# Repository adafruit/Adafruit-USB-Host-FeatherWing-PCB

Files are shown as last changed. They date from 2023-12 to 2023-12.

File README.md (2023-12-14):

## Adafruit USB Host FeatherWing with MAX3421E PCB

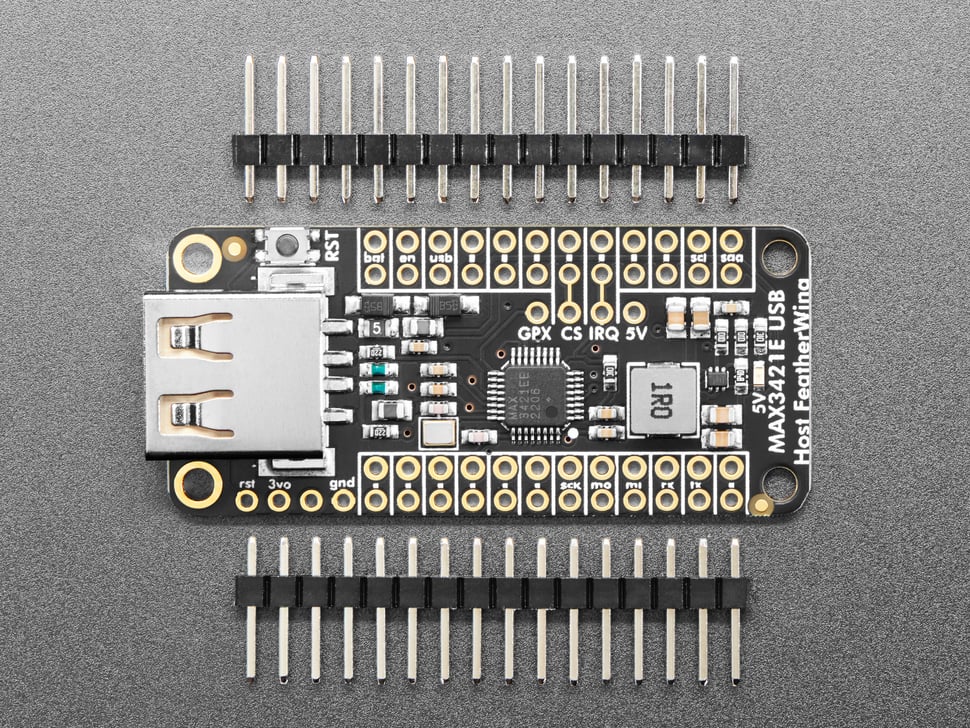
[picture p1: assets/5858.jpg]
<a href="http://www.adafruit.com/products/5858"><br/>
Click here to purchase one from the Adafruit shop</a>

PCB files for the Adafruit USB Host FeatherWing with MAX3421E. 

Format is EagleCAD schematic and board layout
* https://www.adafruit.com/product/5858

### Description

Lots of microcontrollers these days have USB ports on them, to program or debug, act like a keyboard or disk drive, or simply send data between a computer and your firmware. But did you know that you can also add a USB Host port? That means that your microcontroller project can have a keyboard or mouse or disk drive plugged into it - which opens up a huge ecosystem of common off-the-shelf devices that you can now integrate. The Adafruit USB Host FeatherWing makes it easy to add USB Host support, especially now that TinyUSB supports it in the Arduino library as a 'native' interface for host support. 

This Wing uses the MAX3421E - a tried and true USB Host chip. It uses SPI plus an IRQ pin to send data to just about any USB device. Note that because the chip is older, and you're limited to the SPI port speed, you're not going to get blazing 480Mbps high speed data transfer. But for basic HID interfacing, or even reading/writing to a Mass Storage device, it does work quite well. There's a famous USB Host Library that can be used, and it's specialty is AVR support, but also seems to support nRF52 and ESP32. We personally recommend using the TinyUSB Arduino library - however the trade-off is that the chip must have TinyUSB support already which means it's great for RP2040, ESP32-S2 or S3, nRF52840, SAMD21/51 chips. Between the two libraries, just make sure your desired Feather mainboard is supported before purchasing! 

Next to the MAX3421E we have a 5V 1A booster with 500mA fuse, which can provide a nice clean 5V from the USB or Battery power supply. An enable pin is available to power cycle when desired.

Comes as an assembled Wing with some header. Solder on the header and plug into a Feather Mainboard to expand it's capabilities! Don't forget, you need driver support for the MAX3421E (see above for chips that are known working) and unless you're using a generic mouse, keyboard, CDC serial or USB mass storage device you will also need a USB driver that knows how to talk to the device - and writing a driver is non-trivial.

### License

Adafruit invests time and resources providing this open source design, please support Adafruit and open-source hardware by purchasing products from [Adafruit](https://www.adafruit.com)!

Designed by Limor Fried/Ladyada for Adafruit Industries.

Creative Commons Attribution/Share-Alike, all text above must be included in any redistribution. 
See license.txt for additional details.

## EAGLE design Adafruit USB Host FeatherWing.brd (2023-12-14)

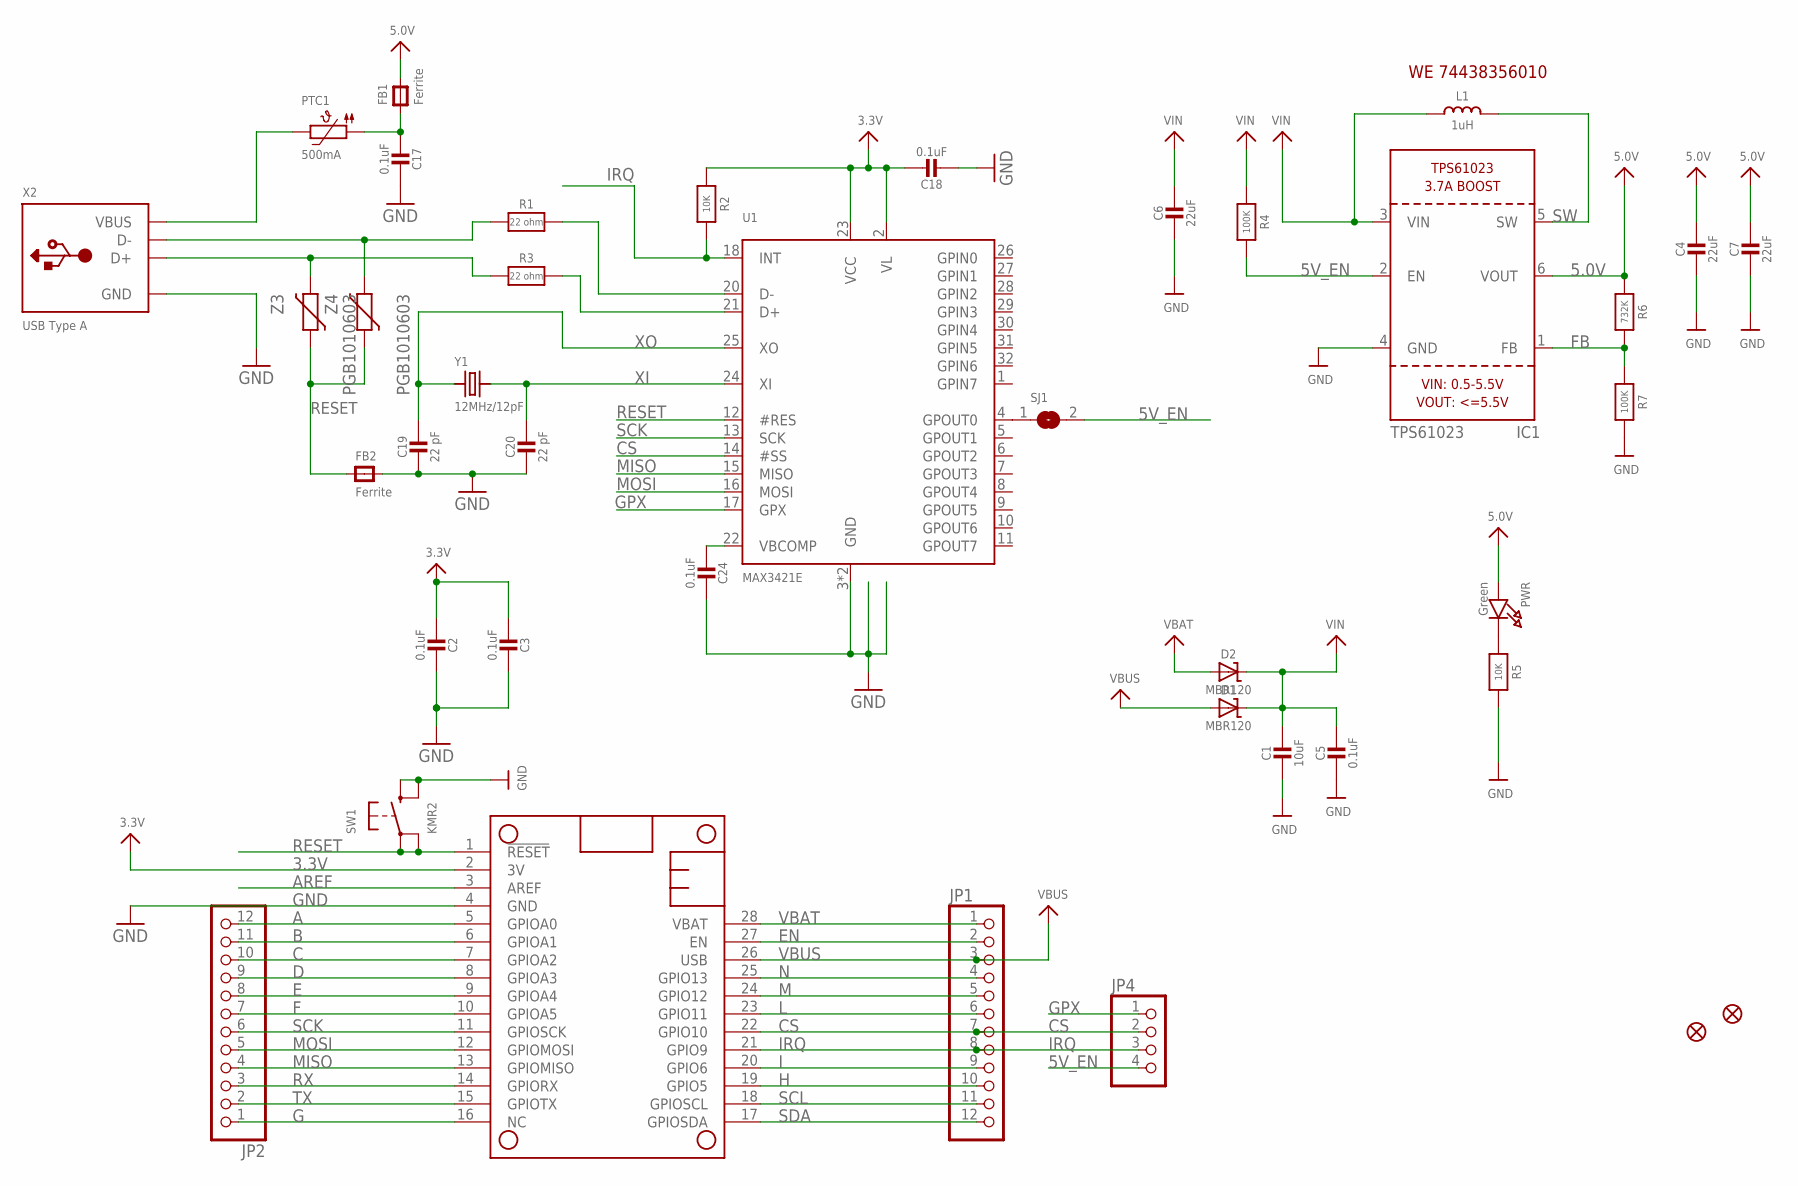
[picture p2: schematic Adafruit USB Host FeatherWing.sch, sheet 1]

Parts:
C1: 10uF; 0805-NO
C2, C3, C5, C17, C18, C24: 0.1uF; 0603-NO
C4, C6, C7: 22uF; 0805-NO
C19, C20: 22 pF; 0603-NO
D1, D2: MBR120; SOD-123
FB1, FB2: Ferrite; 0805-NO
FID1, FID2: FIDUCIAL_1MM
IC1: TPS61023; SOT563
JP1: HEADER-1X12; 1X12_ROUND
JP2: HEADER-1X1276MIL; 1X12_ROUND_76MIL
JP4: HEADER-1X4ROUND; 1X04_ROUND
L1: 1uH; INDUCTOR_5045_SMALLTABS
MS1: FEATHERWING_NODIM
PTC1: 500mA; 0805-NO
PWR: Green; CHIPLED_0603_NOOUTLINE
R1, R3: 22 ohm; 0603-NO
R2, R5: 10K; 0603-NO
R4, R7: 100K; 0603-NO
R6: 732K; 0603-NO
SJ1: SOLDERJUMPER; SOLDERJUMPER_ARROW_NOPASTE
SW1: KMR2; BTN_KMR2_4.6X2.8
U1: MAX3421E; PQFP32_5X5MM
X2: USB Type A; USB_HOST-SMT
Y1: 12MHz/12pF; CRYSTAL_2.5X2
Z3, Z4: PGB1010603; CT/CN0603

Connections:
3.3V: C2.1, C3.1, C18.1, MS1.2 (3V), R2.1, U1.2 (VL), U1.23 (VCC)
5.0V: C4.1, C7.1, FB1.2, IC1.6 (VOUT), PWR.A, R6.1
5V_EN: IC1.2 (EN), JP4.4, R4.2, SJ1.2
A: JP2.12, MS1.5 (GPIOA0)
AREF: MS1.3 (AREF)
B: JP2.11, MS1.6 (GPIOA1)
C: JP2.10, MS1.7 (GPIOA2)
CS: JP1.7, JP4.2, MS1.22 (GPIO10), U1.14 (#SS)
D: JP2.9, MS1.8 (GPIOA3)
E: JP2.8, MS1.9 (GPIOA4)
EN: JP1.2, MS1.27 (EN)
F: JP2.7, MS1.10 (GPIOA5)
FB: IC1.1 (FB), R6.2, R7.1
G: JP2.1, MS1.16 (NC)
GND: C1.2, C2.2, C3.2, C4.2, C5.2, C6.2, C7.2, C17.2, C18.2, C19.1, C20.1, C24.2, FB2.2, IC1.4 (GND), MS1.4 (GND), R5.2, R7.2, SW1.B (S), SW1.B' (S1), U1.3 (GND), U1.19 (GND), X2.GND
GPX: JP4.1, U1.17 (GPX)
H: JP1.10, MS1.19 (GPIO5)
I: JP1.9, MS1.20 (GPIO6)
IRQ: JP1.8, JP4.3, MS1.21 (GPIO9), R2.2, U1.18 (INT)
L: JP1.6, MS1.23 (GPIO11)
M: JP1.5, MS1.24 (GPIO12)
MISO: JP2.4, MS1.13 (GPIOMISO), U1.15 (MISO)
MOSI: JP2.5, MS1.12 (GPIOMOSI), U1.16 (MOSI)
N: JP1.4, MS1.25 (GPIO13)
unnamed: C24.1, U1.22 (VBCOMP)
unnamed: SJ1.1, U1.4 (GPOUT0)
unnamed: FB2.1, Z3.1, Z4.1
unnamed: PWR.C, R5.1
unnamed: R1.1, X2.D-, Z4.2
unnamed: R3.1, X2.D+, Z3.2
unnamed: R1.2, U1.20 (D-)
unnamed: R3.2, U1.21 (D+)
unnamed: PTC1.2, X2.VBUS
unnamed: C17.1, FB1.1, PTC1.1
RESET: MS1.1 (!RESET), SW1.A, SW1.A' (P1), U1.12 (#RES)
RX: JP2.3, MS1.14 (GPIORX)
SCK: JP2.6, MS1.11 (GPIOSCK), U1.13 (SCK)
SCL: JP1.11, MS1.18 (GPIOSCL)
SDA: JP1.12, MS1.17 (GPIOSDA)
SW: IC1.5 (SW), L1.2
TX: JP2.2, MS1.15 (GPIOTX)
VBAT: D2.A, JP1.1, MS1.28 (VBAT)
VBUS: D1.A, JP1.3, MS1.26 (USB)
VIN: C1.1, C5.1, C6.1, D1.C, D2.C, IC1.3 (VIN), L1.1, R4.1
XI: C20.2, U1.24 (XI), Y1.3 (2)
XO: C19.2, U1.25 (XO), Y1.1

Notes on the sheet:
WE 74438356010

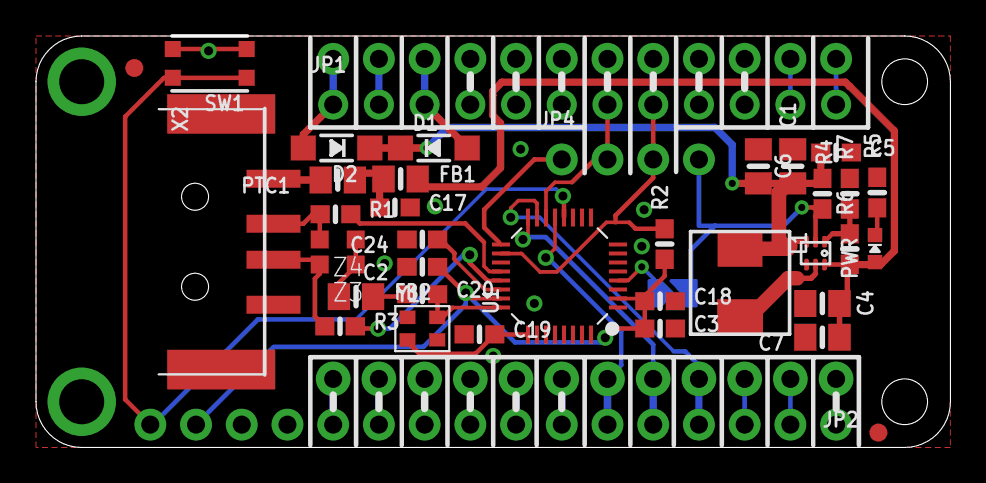
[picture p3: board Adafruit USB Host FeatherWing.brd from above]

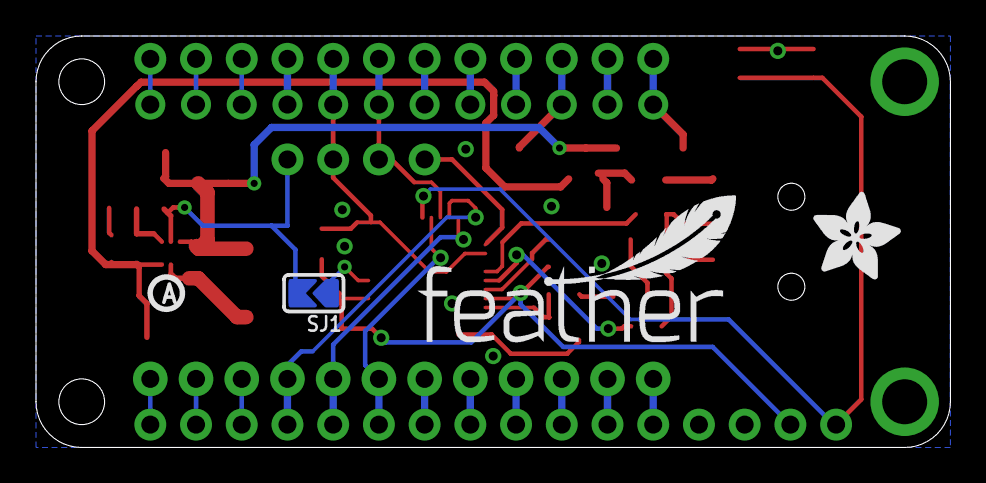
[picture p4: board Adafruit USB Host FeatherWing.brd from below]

Board: 2 copper layers, 50.8 x 22.9 mm, 65 parts (6 on the bottom side), 45 nets.

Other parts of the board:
PLABEL0: PLABEL0
PLABEL1: PLABEL1
PLABEL2: PLABEL2
PLABEL3: PLABEL3
PLABEL4: PLABEL4
PLABEL5: PLABEL5
PLABEL6: PLABEL6
PLABEL7: PLABEL7
PLABEL8: PLABEL8
PLABEL9: PLABEL9
PLABEL10: PLABEL10
PLABEL11: PLABEL11
PLABEL12: PLABEL12
PLABEL13: PLABEL13
PLABEL14: PLABEL14
PLABEL15: PLABEL15
PLABEL16: PLABEL16
PLABEL17: PLABEL17
PLABEL18: PLABEL18
PLABEL19: PLABEL19
PLABEL20: PLABEL20
PLABEL21: PLABEL21
U$20: FEATHERLOGO_MED
U$22: ADAFRUIT_5MM
U$26: PCBFEAT-REV-040

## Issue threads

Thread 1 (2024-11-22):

Pin labels not clear enough on pictures.  Please provide a labelled pinout

Andy2No, 2024-11-22:
The Pin labels for the USB Host Featherwing are not clear enough in the only relevant documentation, which is just a photograph of the board.

Please provide a labelled pinout diagram, to show how to connect this to other devices, i.e. not just as an add-on to Adafruit Feathers.

See: https://learn.adafruit.com/adafruit-usb-host-featherwing-with-max3421e/pinouts

- all there is under "Pinouts" is a photograph of each side of the board, and the labeling, as shown, is not clear enough to provide the necessary information.  All it needs is a clear text label for each pin, and a line or arrow to the pin.
